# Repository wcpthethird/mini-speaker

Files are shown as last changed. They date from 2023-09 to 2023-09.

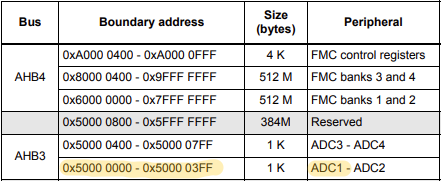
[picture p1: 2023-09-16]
Reference/ADCDataRegisterRM2.png

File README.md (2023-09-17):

# Mini Speaker
## Overview
The goal of this project is to convert the guitar amplifer from LEGO set no. 21379 into a functional desktop speaker. Modifications include original and custom 3D-printed parts to support peripherals integration and PCB support. The LEGO amplifier is modeled in Fusion 360 in an effort to assist in the project's vizualization.

### [Design](3D_Model)
Features of the amp are exploited to increase the level of user-interaction with the device. Knobs along the front of the control panel house a small 3D-printed coupling device to actuate potentiometers that control volume and other effects. One of the knobs is replaced with a tactile switch to control the device's power state. A 2.5mm jack replaces its LEGO counterpart near the left end of the control panel, supported by two 3D-printed. An LED is placed behind the ruby near the right end of the control panel as a power indicator. A 57mm speaker is hidden within the speaker assembly, adhered to a 3D-printed plate at the center.

### [PCB](PCB)
The main PCB leverages an STM32F-series microcontroller and a 4-layer stackup with internal signal/power layers. It is pinned inside the rear enclosure of the amp using a spare knob from the control panel, supported by two 3D-printed bricks surrounding a USB-C port which powers the device. The auxilliary PCB with the ON/OFF switch is connected to the control panel PCB, which is connected to the main PCB via flex cable.

### [Firmware](MiniSpeaker_STM32)
Using ST's MCU software development tools, the main PCB is programmed to convert an analog signal to digital, apply some filtering and effects, and convert the digital signal back to analog where it is driven onto the output. Peripheral controls are also read via A/D converter and are implemented as volume and effects control parameters. Low-power mode, "standby," is leveraged to support the ON/OFF switch, events of which are read via GPIO and Wake-Up pins near-simultaneously (GPIO is hardware delayed).

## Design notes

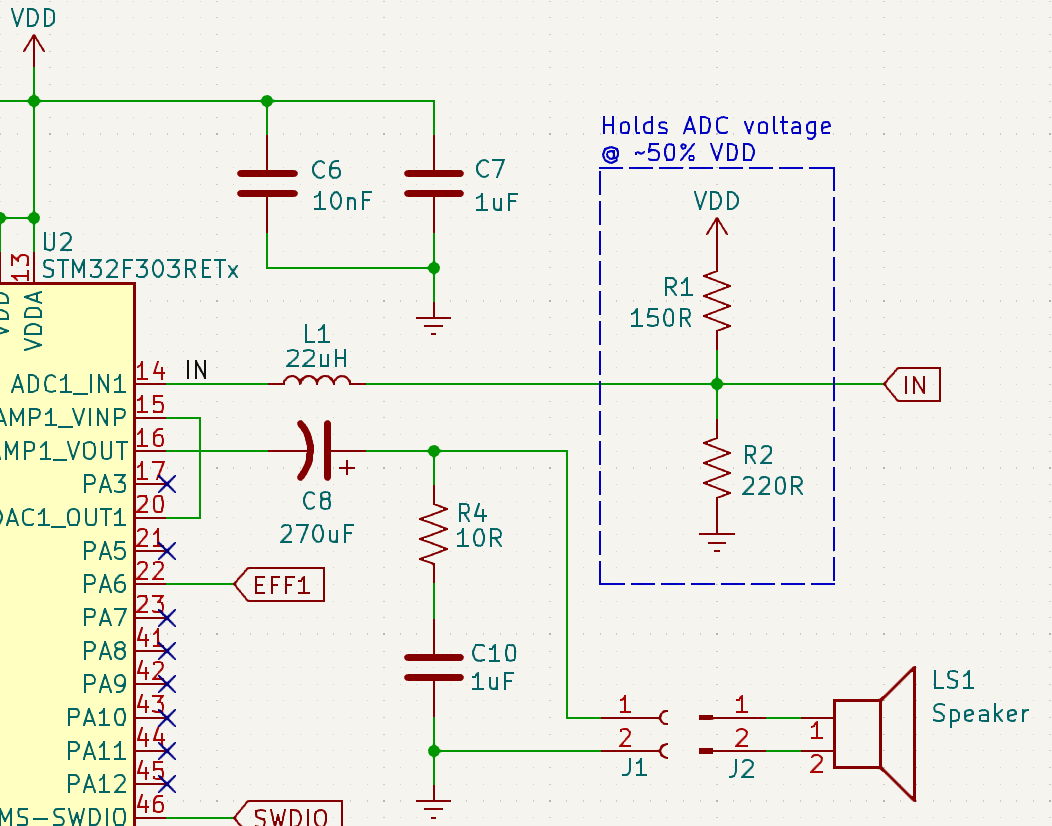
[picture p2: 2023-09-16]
Reference/AnalogCircuit.png

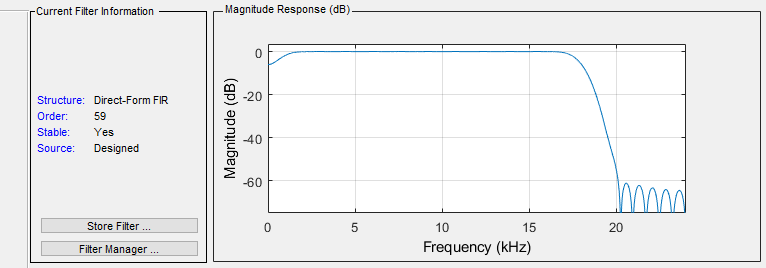
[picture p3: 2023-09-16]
Reference/BPFilter1.png

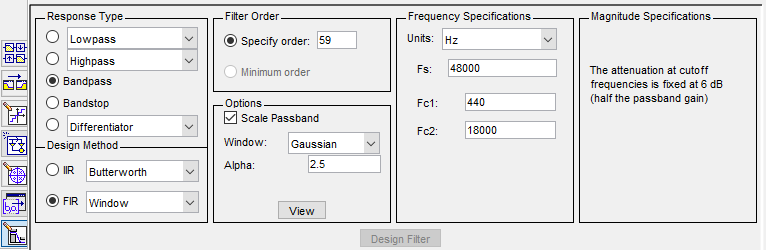
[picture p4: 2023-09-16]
Reference/BPFilter2.png

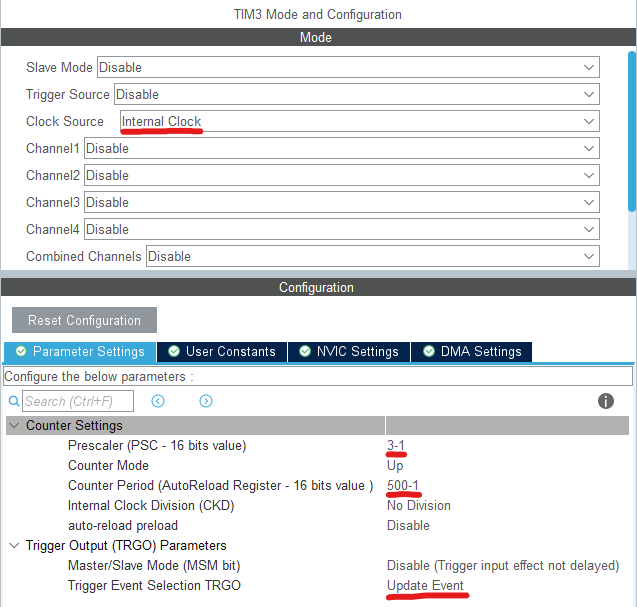
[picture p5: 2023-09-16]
Reference/TIM3ConfigCube.png

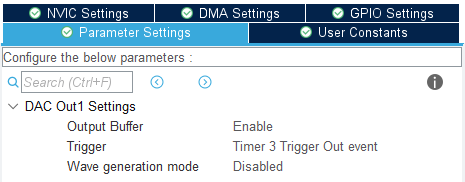
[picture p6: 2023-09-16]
Reference/DACConfigCube.png

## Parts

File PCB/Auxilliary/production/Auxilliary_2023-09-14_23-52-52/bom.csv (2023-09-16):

Designator | Footprint | Quantity | Value | LCSC Part #
C1 | 0402 | 1 | 1uF | C389008
J1, J2 | TestPoint_Pad_D2.0mm | 2 | Conn_01x01_Socket
J3 | PinSocket_2x02_P2.54mm_Vertical | 1 | Conn_01x04_Socket
R1 | 0402 | 1 | 4K7 | C2935240
SW1 | SW_PUSH_6mm_H13mm | 1 | SW_Push

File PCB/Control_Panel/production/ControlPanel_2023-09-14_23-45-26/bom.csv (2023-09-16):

Designator | Footprint | Quantity | Value | LCSC Part #
D1 | LED_D3.0mm_Horizontal_O6.35mm_Z2.0mm | 1 | LED
J1 | PinHeader_2x02_P2.54mm_Vertical_SMD | 1 | Conn_01x04_Pin
J2 | TE_1-1734248-2 | 1 | TE_Conn_1-1734248-2
R3 | 0402 | 1 | 3K3 | C137874
RV1, RV2, RV3, RV4 | Potentiometer_Bourns_3314R-1_Vertical_Hole | 4 | R_Potentiometer_US

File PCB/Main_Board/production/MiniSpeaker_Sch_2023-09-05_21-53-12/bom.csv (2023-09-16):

Designator | Footprint | Quantity | Value | LCSC Part #
C1 | 0603 | 1 | 4.7uF | C152930
C10, C11, C14, C7 | 0402 | 4 | 1uF | C389008
C12 | CP_EIA-3216-18_Kemet-A | 1 | 10uF | C124856
C13 | CP_EIA-3216-18_Kemet-A | 1 | 22uF | C124838
C15, C6 | 0402 | 2 | 10nF | C527020
C2, C3, C4, C5, C9 | 0402 | 5 | 100nF | C129131
C8 | CP_Elec_6.3x7.7 | 1 | 270uF | C178573
J10 | USB_C_Receptacle_GCT_USB4135-GF-A_6P_TopMnt_Horizontal | 1 | USB-C | C2689835
J11, J2, J5, J6 | TE_440054-2_1x02_P2.00mm_Vertical | 4 | Conn_01x02_Socket
J14 | PinHeader_2x03_P2.54mm_Vertical | 1 | SWD | C358692
J8 | TE_440054-3_1x03_P2.00mm_Vertical | 1 | Conn_01x03_Socket
L1 | 0603 | 1 | 22uH | C2041591
R1 | 0402 | 1 | 150R | C227304
R10, R9 | 0402 | 2 | 5K1 | C144745
R2 | 0402 | 1 | 220R | C137899
R3 | 0402 | 1 | 0R | C4288031
R4 | 0402 | 1 | 10R | C144729
R5 | 0402 | 1 | 3K3 | C137874
R6, R8 | 0402 | 2 | 4K7 | C2935240
R7 | 0402 | 1 | 1K | C106235
U1 | SOT-223-3_TabPin2 | 1 | AZ1117-3.3 | C110474
U2 | LQFP-64_10x10mm_P0.5mm | 1 | STM32F303RETx | C183214

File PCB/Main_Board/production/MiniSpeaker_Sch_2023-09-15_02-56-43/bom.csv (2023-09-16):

Designator | Footprint | Quantity | Value | LCSC Part #
C1 | 0603 | 1 | 4.7uF | C152930
C11, C7 | 0402 | 2 | 1uF | C389008
C12 | CP_EIA-3216-18_Kemet-A | 1 | 10uF | C124856
C13 | CP_EIA-3216-18_Kemet-A | 1 | 22uF | C124838
C15, C6 | 0402 | 2 | 10nF | C527020
C2, C3, C4, C5, C9 | 0402 | 5 | 100nF | C129131
C8 | CP_Elec_6.3x7.7 | 1 | 270uF | C178573
H1 | MountingHole_4mm | 1 | MountingHole
J1 | TE_1-1734248-2 | 1 | TE_Conn_1-1734248-2 | C590853
J14 | PinHeader_2x03_P2.54mm_Vertical | 1 | SWD | C358692
J2 | GCT_USB4130-GF-A_REVA | 1 | USB-C | C5187463
J6 | TE_440054-2_1x02_P2.00mm_Vertical | 1 | Conn_01x02_Socket
L1 | 0603 | 1 | 22uH | C2041591
R1 | 0402 | 1 | 150R | C227304
R10, R9 | 0402 | 2 | 5K1 | C144745
R2 | 0402 | 1 | 220R | C137899
R3 | 0402 | 1 | 0R | C4288031
R4 | 0402 | 1 | 10R | C144729
R6 | 0402 | 1 | 4K7 | C2935240
U1 | SOT-223-3_TabPin2 | 1 | AZ1117-3.3 | C110474
U2 | LQFP-64_10x10mm_P0.5mm | 1 | STM32F303RETx | C183214

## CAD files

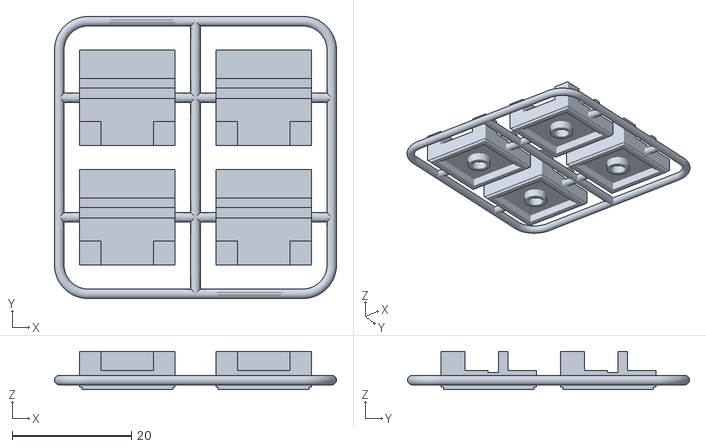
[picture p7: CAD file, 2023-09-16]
3D_Model/STL/Print/Board Support BH_Array v3.stl
47.2 x 47.2 x 6.40

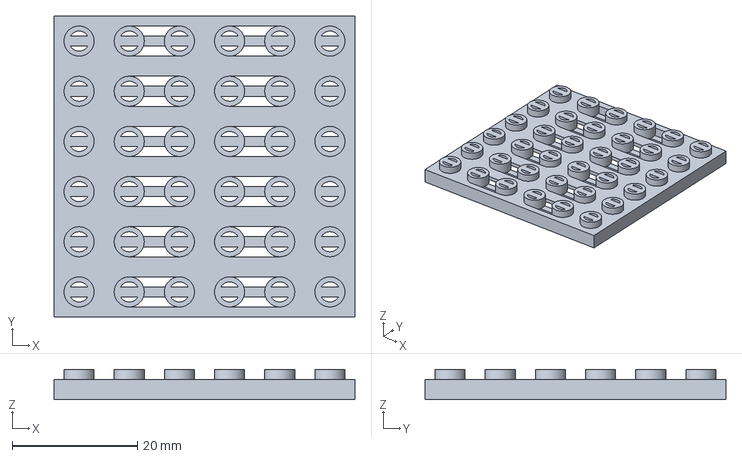
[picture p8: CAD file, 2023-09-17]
3D_Model/STP/6x6 Speaker Grate v7.step
48.0 x 48.0 x 4.80 mm

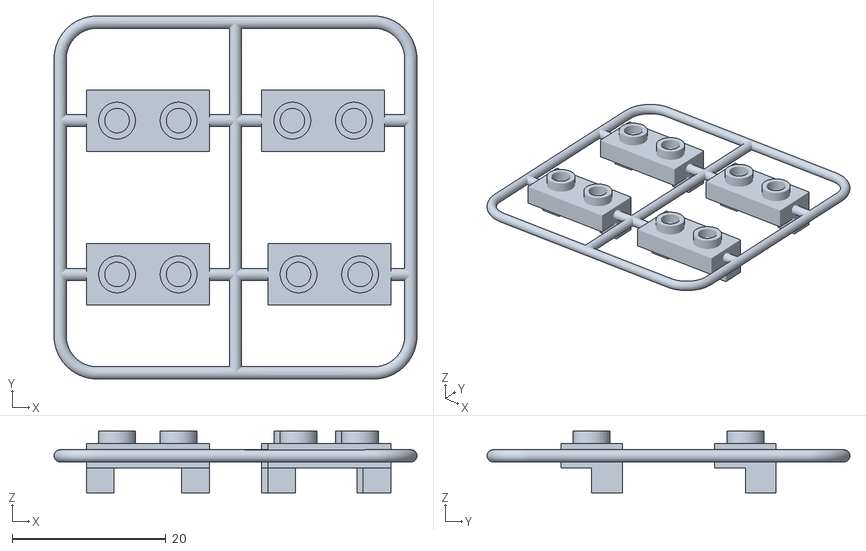
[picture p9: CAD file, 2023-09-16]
3D_Model/STL/Print/Board Support TH_Array v3.stl
47.2 x 47.2 x 8.00

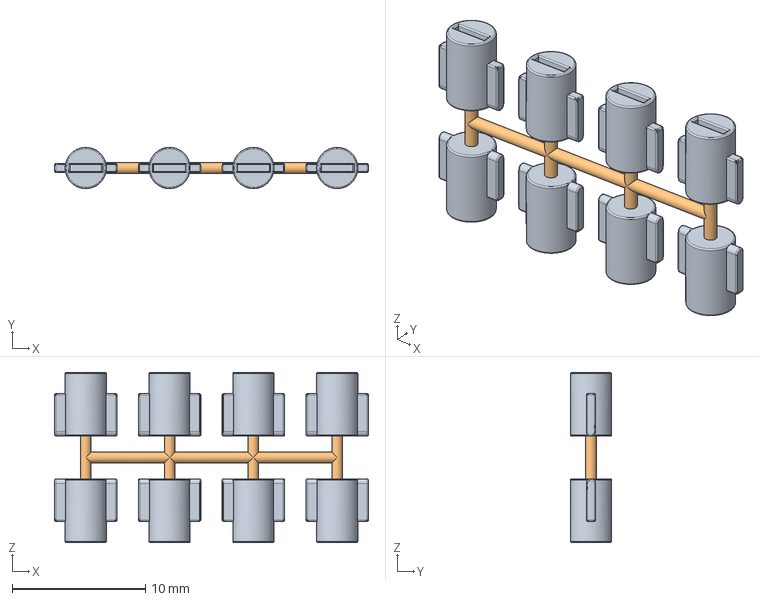
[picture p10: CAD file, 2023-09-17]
3D_Model/STP/Coupler_Array v4.step
23.6 x 3.10 x 12.8 mm
Coupler x 8

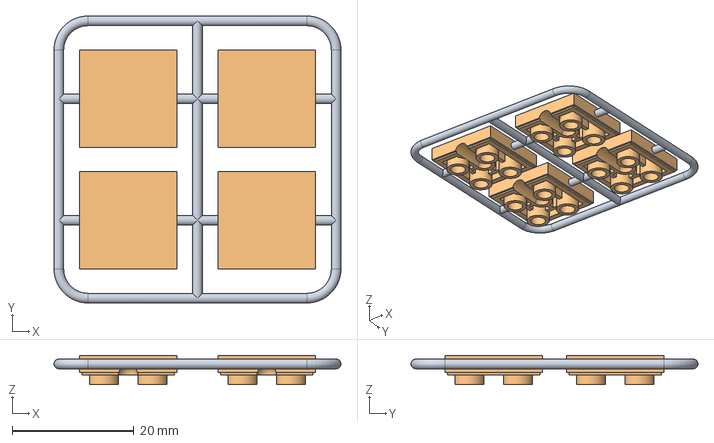
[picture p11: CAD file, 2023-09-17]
3D_Model/STP/Speaker_Array v2.step
47.2 x 47.2 x 4.80 mm
Print Frame
2x2 Speaker x 4

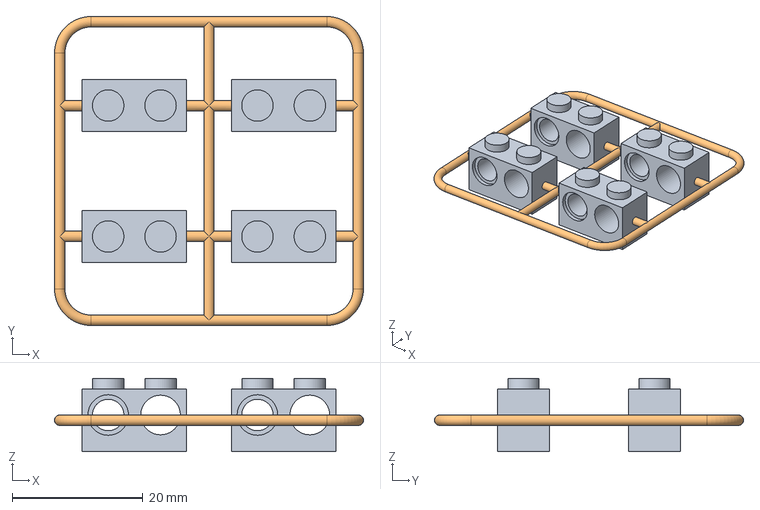
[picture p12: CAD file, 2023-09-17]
3D_Model/STP/2.5mm FH_Array v2.step
47.2 x 47.2 x 11.2 mm
1x2 2.5mm FH x 4

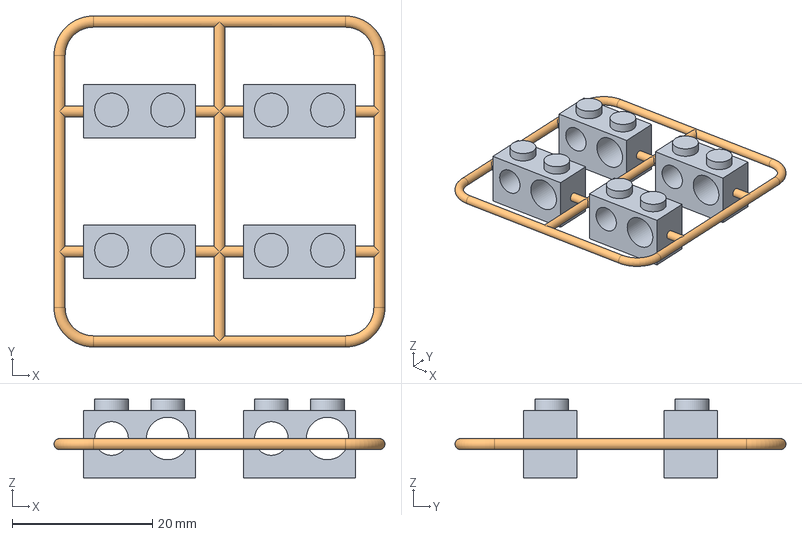
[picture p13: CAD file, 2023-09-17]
3D_Model/STP/2.5mm RH_Array v1.step
47.2 x 47.2 x 11.2 mm
1x2 2.5mm RH x 4

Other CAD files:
3D_Model/STP/Board Support BH_Array v5.step
3D_Model/STP/Board Support TH_Array v4.step
3D_Model/STL/Print/2.5mm FH_Array v2.stl
3D_Model/STL/Print/2.5mm RH_Array v1.stl
3D_Model/STL/Print/6x6 Speaker Grate v7.stl
3D_Model/STL/Print/Coupler_Array v4.stl
3D_Model/STL/Print/Speaker_Array v2.stl

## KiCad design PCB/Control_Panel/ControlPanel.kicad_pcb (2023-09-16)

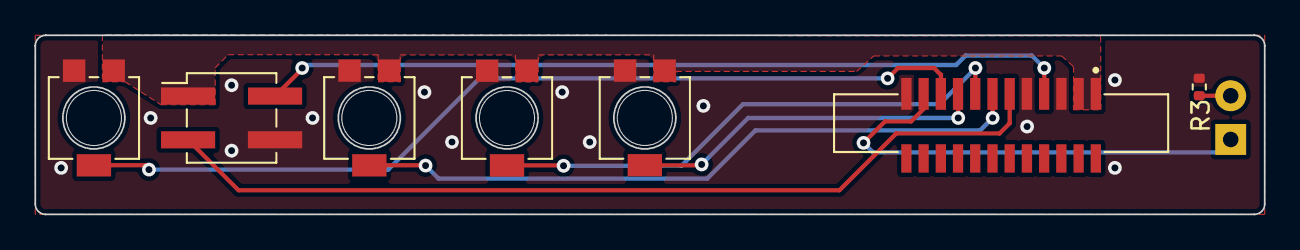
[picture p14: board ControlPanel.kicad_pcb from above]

Board: 2 copper layers, 71.4 x 10.4 mm, 8 parts (0 on the bottom side), 10 nets.

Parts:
D1: LED; LED_D3.0mm_Horizontal_O6.35mm_Z2.0mm
J1: Conn_01x04_Pin; PinHeader_2x02_P2.54mm_Vertical_SMD
J2: TE_Conn_1-1734248-2; TE_1-1734248-2
R3: 3K3; R_0402_1005Metric
RV1, RV2, RV3, RV4: R_Potentiometer_US; Potentiometer_Bourns_3314R-1_Vertical_Hole

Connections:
BTN: J1.3, J2.6
EFF1: J2.7, RV2.2
EFF2: J2.8, RV3.2
EFF3: J2.9, RV4.2
Earth: J1.4, J2.3, J2.5, J2.12, R3.2, RV1.3, RV2.3, RV3.3, RV4.3
IN: J1.2, J2.4
LED: D1.1 (K), J2.11
unnamed: D1.2 (A), R3.1
VDD: J1.1, J2.1, J2.2, RV1.1, RV2.1, RV3.1, RV4.1
VOL: J2.10, RV1.2

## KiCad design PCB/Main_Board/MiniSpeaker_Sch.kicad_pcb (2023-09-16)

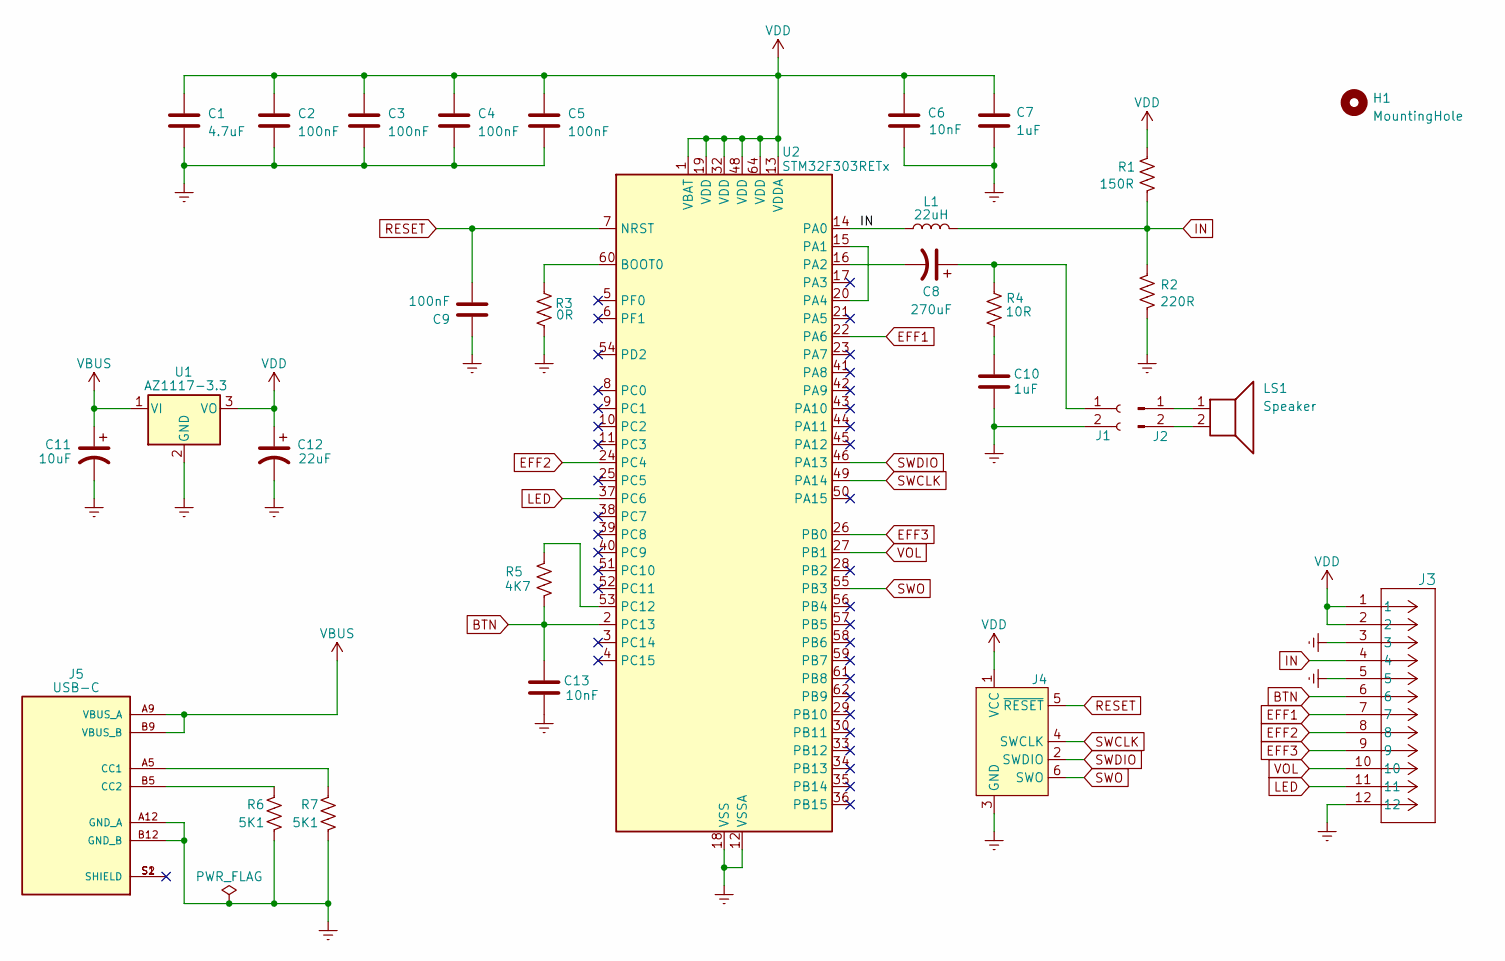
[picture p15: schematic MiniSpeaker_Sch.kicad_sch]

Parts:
C1: 4.7uF; C_0603_1608Metric; LCSC C152930
C2, C3, C4, C5, C9: 100nF; C_0402_1005Metric; LCSC C129131
C6, C13: 10nF; C_0402_1005Metric; LCSC C527020
C7, C10: 1uF; C_0402_1005Metric; LCSC C389008
C8: 270uF; CP_Elec_6.3x7.7; LCSC C178573
C11: 10uF; CP_EIA-3216-18_Kemet-A; LCSC C124856
C12: 22uF; CP_EIA-3216-18_Kemet-A; LCSC C124838
H1: MountingHole; MountingHole_4mm
J1: Conn_01x02_Socket; TE_440054-2_1x02_P2.00mm_Vertical
J2: Conn_01x02_Pin
J3: TE_Conn_1-1734248-2; TE_1-1734248-2; LCSC C590853
J4: SWD; PinHeader_2x03_P2.54mm_Vertical; LCSC C358692
J5: USB-C; GCT_USB4130-GF-A_REVA; LCSC C5187463
L1: 22uH; L_0603_1608Metric; LCSC C2041591
LS1: Speaker
R1: 150R; R_0402_1005Metric; LCSC C227304
R2: 220R; R_0402_1005Metric; LCSC C137899
R3: 0R; R_0402_1005Metric; LCSC C4288031
R4: 10R; R_0402_1005Metric; LCSC C144729
R5: 4K7; R_0402_1005Metric; LCSC C2935240
R6, R7: 5K1; R_0402_1005Metric; LCSC C144745
U1: AZ1117-3.3; SOT-223-3_TabPin2; LCSC C110474
U2: STM32F303RETx; LQFP-64_10x10mm_P0.5mm; LCSC C183214

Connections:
BTN: C13.2, J3.6, R5.1, U2.2 (PC13)
EFF1: J3.7, U2.22 (PA6)
EFF2: J3.8, U2.24 (PC4)
EFF3: J3.9, U2.26 (PB0)
Earth: C1.2, C2.2, C3.2, C4.2, C5.2, C6.2, C7.2, C9.1, C10.2, C11.2, C12.2, C13.1, J1.2, J3.3, J3.5, J3.12, J4.3 (GND), J5.A12 (GND_A), J5.B12 (GND_B), R2.2, R3.1, R6.2, R7.2, U1.2 (GND), U2.12 (VSSA), U2.18 (VSS), U2.31 (VSS), U2.47 (VSS), U2.63 (VSS)
IN: J3.4, L1.1, L1.2, R1.1, R2.1, U2.14 (PA0)
LED: J3.11, U2.37 (PC6)
unnamed: C10.1, R4.2
unnamed: C8.1, J1.1, R4.1
unnamed: J2.1, LS1.1
unnamed: J2.2, LS1.2
unnamed: J5.A5 (CC1), R7.1
unnamed: J5.B5 (CC2), R6.1
unnamed: R3.2, U2.60 (BOOT0)
unnamed: U2.15 (PA1), U2.20 (PA4)
unnamed: C8.2, U2.16 (PA2)
unnamed: R5.2, U2.53 (PC12)
RESET: C9.2, J4.5 (~RESET), U2.7 (NRST)
SWCLK: J4.4 (SWCLK), U2.49 (PA14)
SWDIO: J4.2 (SWDIO), U2.46 (PA13)
SWO: J4.6 (SWO), U2.55 (PB3)
VBUS: C11.1, J5.A9 (VBUS_A), J5.B9 (VBUS_B), U1.1 (VI)
VDD: C1.1, C2.1, C3.1, C4.1, C5.1, C6.1, C7.1, C12.1, J3.1, J3.2, J4.1 (VCC), R1.2, U1.3 (VO), U2.1 (VBAT), U2.13 (VDDA), U2.19 (VDD), U2.32 (VDD), U2.48 (VDD), U2.64 (VDD)
VOL: J3.10, U2.27 (PB1)

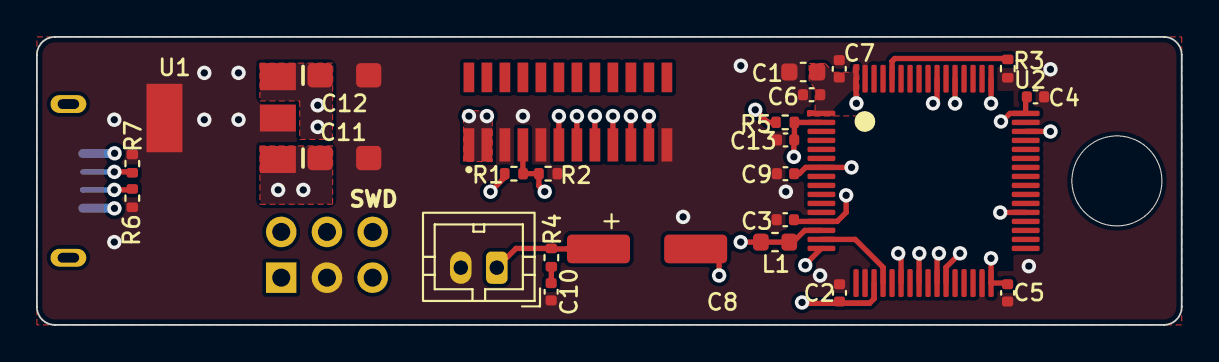
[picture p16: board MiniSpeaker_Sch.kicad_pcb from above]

Board: 4 copper layers, 63.6 x 16.0 mm, 28 parts (1 on the bottom side), 22 nets.

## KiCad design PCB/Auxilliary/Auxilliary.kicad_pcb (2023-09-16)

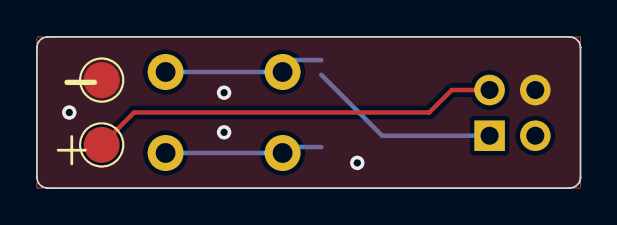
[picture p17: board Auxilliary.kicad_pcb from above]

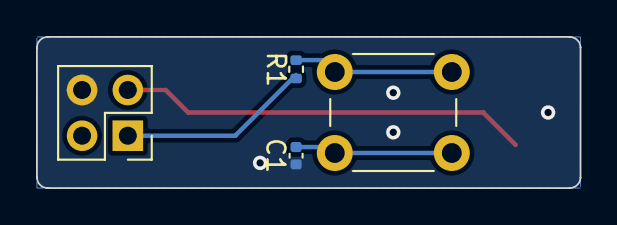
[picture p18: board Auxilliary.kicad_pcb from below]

Board: 2 copper layers, 30.2 x 8.4 mm, 6 parts (4 on the bottom side), 5 nets.

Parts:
C1: 1uF; C_0402_1005Metric
J1, J2: Conn_01x01_Socket; TestPoint_Pad_D2.0mm
J3: Conn_01x04_Socket; PinSocket_2x02_P2.54mm_Vertical
R1: 4K7; R_0402_1005Metric
SW1: SW_Push; SW_PUSH_6mm_H13mm

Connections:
Earth: C1.2, J2.1, J3.4
IN: J1.1, J3.2
unnamed: C1.1, SW1.1
unnamed: R1.1, SW1.2
VDD: J3.1, R1.2

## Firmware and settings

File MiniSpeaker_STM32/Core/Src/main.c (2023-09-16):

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
/* Includes ------------------------------------------------------------------*/
#include "main.h"

/* USER CODE BEGIN Includes */
#include <stdlib.h>
#include <stdio.h>
#include <errno.h>
#include "arm_math.h"
/* USER CODE END Includes */

/* USER CODE BEGIN PD */
#define ADC1_BITS 12
#define ADC2_BITS 8
#define BIAS 2048
#define BLOCK_SIZE 1024
#define FIR_BLOCK_SIZE 256
#define NUM_TAPS 40
/* USER CODE END PD */

ADC_HandleTypeDef hadc1;
ADC_HandleTypeDef hadc2;
DMA_HandleTypeDef hdma_adc1;
DMA_HandleTypeDef hdma_adc2;

DAC_HandleTypeDef hdac1;
DMA_HandleTypeDef hdma_dac1_ch1;

OPAMP_HandleTypeDef hopamp2;

TIM_HandleTypeDef htim2;
TIM_HandleTypeDef htim3;

/* USER CODE BEGIN PV */
const uint32_t *csr = (uint32_t*)0x40007004; // Power control/status register

const uint16_t adc1Res = pow(2, ADC1_BITS);
const uint16_t adc2Res = pow(2, ADC2_BITS);

const uint16_t numBlocks = BLOCK_SIZE/FIR_BLOCK_SIZE;

const uint32_t dacAlignment = DAC_ALIGN_12B_R;
const uint32_t dacChannel = DAC_CHANNEL_1;

const float32_t gain = 2.0f;

// Coefficients for FIR filter
static float32_t firTaps[NUM_TAPS] =
{
    -0.0002882429108,-0.001982697519,-0.001052211621,-0.0001040179195, -0.00479822699,
    -0.003936131019, 0.001096982276, -0.00907566119, -0.01158319786, 0.004249109887,
     -0.01242559683,  -0.0281526614, 0.009637908079,-0.007540509105, -0.06024632975,
      0.01590904966,   0.0270492807,  -0.1385083944,  0.02024864219,   0.5081212521,
       0.5081212521,  0.02024864219,  -0.1385083944,   0.0270492807,  0.01590904966,
     -0.06024632975,-0.007540509105, 0.009637908079,  -0.0281526614, -0.01242559683,
     0.004249109887, -0.01158319786, -0.00907566119, 0.001096982276,-0.003936131019,
     -0.00479822699,-0.0001040179195,-0.001052211621,-0.001982697519,-0.0002882429108
};

volatile uint16_t adc1DataIn[BLOCK_SIZE]; // Line audio data from ADC1 input
float32_t         adc1DataOut[BLOCK_SIZE];
volatile uint16_t *adc1DataInPtr;
float32_t         *adc1DataOutPtr;

volatile uint8_t  adc2Data; // Volume control data from ADC2 input
float32_t         vol = 1;

float32_t dacDataIn[BLOCK_SIZE];
uint16_t  dacDataOut[BLOCK_SIZE];
float32_t *dacDataInPtr = &dacDataIn[0];
uint16_t  *dacDataOutPtr = &dacDataOut[0];

arm_fir_instance_f32 fir;
float32_t firState[NUM_TAPS + FIR_BLOCK_SIZE - 1];
float32_t *inF32 = &adc1DataOut[0];
float32_t *outF32 = &dacDataIn[0];
/* USER CODE END PV */

void SystemClock_Config(void);
static void MX_GPIO_Init(void);
static void MX_DMA_Init(void);
static void MX_ADC1_Init(void);
static void MX_DAC1_Init(void);
static void MX_TIM3_Init(void);
static void MX_OPAMP2_Init(void);
static void MX_TIM2_Init(void);
static void MX_ADC2_Init(void);
/* USER CODE BEGIN PFP */
void ADC_ProcessHalf(void);
void DAC_Process(void);
void Power_Toggle(void);
/* USER CODE END PFP */

/**
  * @brief  The application entry point.
  * @retval int
  */
int main(void)
{
  /* USER CODE BEGIN 1 */
  uint32_t stdby = *csr>>1&1; // Standby flag for low-power mode

  /* USER CODE END 1 */

  /* MCU Configuration--------------------------------------------------------*/

  /* Reset of all peripherals, Initializes the Flash interface and the Systick. */
  HAL_Init();

  /* USER CODE BEGIN Init */
  HAL_PWR_EnableWakeUpPin(PWR_WAKEUP_PIN3);

  /* USER CODE END Init */

  /* Configure the system clock */
  SystemClock_Config();

  /* Initialize all configured peripherals */
  MX_GPIO_Init();
  MX_DMA_Init();
  MX_ADC1_Init();
  MX_DAC1_Init();
  MX_TIM3_Init();
  MX_OPAMP2_Init();
  MX_TIM2_Init();
  MX_ADC2_Init();
  /* USER CODE BEGIN 2 */
  // Enter standby mode on initial boot
  !stdby ? HAL_PWR_EnterSTANDBYMode() : HAL_GPIO_TogglePin(GPIOE, GPIO_PIN_0);

  arm_fir_init_f32(&fir, NUM_TAPS, &firTaps[0], &firState[0], FIR_BLOCK_SIZE);

  HAL_TIM_Base_Start(&htim2);
  HAL_TIM_Base_Start(&htim3);
  HAL_OPAMP_Start(&hopamp2);

  HAL_ADC_Start_DMA(&hadc1, (uint32_t*)adc1DataIn, BLOCK_SIZE);
  HAL_ADC_Start_DMA(&hadc2, (uint32_t*)&adc2Data, 1);
  HAL_DAC_Start_DMA(&hdac1, dacChannel, (uint32_t*)dacDataOut, BLOCK_SIZE, dacAlignment);

  /* USER CODE END 2 */

  /* Infinite loop */
  /* USER CODE BEGIN WHILE */
  while (1)
  {
	vol = (float)adc2Data / adc2Res; // Value between 0 and 1; multiplier for volume
	// Apply filter and move DAC data to output
	for (int i=0; i<numBlocks; i++)
	{
	  // Apply filter in blocks
	  arm_fir_f32(&fir, inF32 + (i * FIR_BLOCK_SIZE), outF32 + (i * FIR_BLOCK_SIZE), FIR_BLOCK_SIZE);
	}
	// Move filtered data to output
	DAC_Process();
    /* USER CODE END WHILE */

    /* USER CODE BEGIN 3 */
  }
  /* USER CODE END 3 */
}

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
/* USER CODE BEGIN 4 */
/* Moves data from ADC in to ADC out; compensates for bias */
void ADC_ProcessHalf(void)
{
  for (int i = 0; i < (BLOCK_SIZE * 0.5f); i++)
  {
    adc1DataOutPtr[i] = (float)(adc1DataInPtr[i] - BIAS) * 2.0f;
  }
}

/* Move data from DAC in to DAC out, apply volume and gain calculations to samples; compensate for bias */
void DAC_Process(void)
{
  for (int i = 0; i < BLOCK_SIZE; i++)
  {
    dacDataOutPtr[i] = (int)(dacDataInPtr[i] * vol) + BIAS; // Apply volume multiplier and compensate for bias
  }
}

/* Set pointers to first half of ADC buffer; move first half of data from ADC in to ADC out */
void HAL_ADC_ConvHalfCpltCallback(ADC_HandleTypeDef* hadc)
{
  adc1DataInPtr = &adc1DataIn[0];
  adc1DataOutPtr = &adc1DataOut[0];
  ADC_ProcessHalf();
}

/* Set pointers to second half of ADC buffer; move second half of data from ADC in to ADC out */
void HAL_ADC_ConvCpltCallback(ADC_HandleTypeDef* hadc)
{
  adc1DataInPtr = &adc1DataIn[BLOCK_SIZE / 2];
  adc1DataOutPtr = &adc1DataOut[BLOCK_SIZE / 2];
  ADC_ProcessHalf();
}

/* Enter standby mode */
void HAL_GPIO_EXTI_Callback(uint16_t GPIO_Pin)
{
  __HAL_PWR_CLEAR_FLAG(PWR_FLAG_WU); // Clear flag to prevent immediate wake-up
  HAL_GPIO_TogglePin(GPIOE, GPIO_PIN_0); // Toggle power indication led
  HAL_PWR_EnterSTANDBYMode();
}
/* USER CODE END 4 */
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


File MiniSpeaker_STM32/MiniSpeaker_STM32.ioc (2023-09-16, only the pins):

Mcu.UserName=STM32F303ZETx
PA0.Signal=ADC1_IN1
PA13.Signal=SYS_JTMS-SWDIO
PA14.Signal=SYS_JTCK-SWCLK
PA4.Signal=COMP_DAC11_group
PA5.Signal=ADC2_IN2
PA6.Signal=OPAMP2_VOUT
PA7.Signal=OPAMP2_VINP
PD8.Signal=USART3_TX
PD9.Signal=USART3_RX
PE0.GPIO_Label=PWR_LED
PE0.Signal=GPIO_Output
PE15.GPIO_Label=ONOFF_SW
PE15.Signal=GPXTI15
PE6.Signal=SYS_WKUP3
PF0-OSC_IN.Signal=RCC_OSC_IN
PF1-OSC_OUT.Signal=RCC_OSC_OUT

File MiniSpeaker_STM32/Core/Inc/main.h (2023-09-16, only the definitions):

#define ONOFF_SW_Pin GPIO_PIN_15
#define ONOFF_SW_GPIO_Port GPIOE
#define ONOFF_SW_EXTI_IRQn EXTI15_10_IRQn
#define PWR_LED_Pin GPIO_PIN_0
#define PWR_LED_GPIO_Port GPIOE

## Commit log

2023-09-16 Add Main Board files
    [MiniSpeaker_Sch.kicad_pcb, MiniSpeaker_Sch.kicad_sch, bom.csv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]
2023-09-16 Add Control Panel files
    [ControlPanel-B_Cu.gbr, ControlPanel-B_Mask.gbr, ControlPanel-B_Paste.gbr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]
2023-09-16 Add Auxilliary files
    [Auxilliary-B_Cu.gbr, Auxilliary-B_Mask.gbr, Auxilliary-B_Paste.gbr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]
2023-09-16 Add STM32 code files
2023-09-16 Add Reference files
    [linenoise.xlsx]
2023-09-16 Add validation files
    [linenoise.csv]
2023-09-16 Update Reference files
    [linenoise.xlsx]
2023-09-16 Add 3D Model files
    [2.5mm FH_Array v2.step, 2.5mm FH_Array v2.stl, 2.5mm RH_Array v1.step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]
2023-09-16 Chore: Consolidate PCB files (#2)
    * Chore: Clarify standby comment
    * Chore: Consolidate PCB files
    [Auxilliary-B_Cu.gbr, Auxilliary-B_Mask.gbr, Auxilliary-B_Paste.gbr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]
2023-09-17 Add "Print" folder to 3D model directory
    Clean up inconsistent file names
    [2.5mm FH_Array v2.step, 2.5mm FH_Array v2.stl, 2.5mm RH_Array v1.step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]

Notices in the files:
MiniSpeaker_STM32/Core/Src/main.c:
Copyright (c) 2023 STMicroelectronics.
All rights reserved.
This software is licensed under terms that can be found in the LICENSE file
